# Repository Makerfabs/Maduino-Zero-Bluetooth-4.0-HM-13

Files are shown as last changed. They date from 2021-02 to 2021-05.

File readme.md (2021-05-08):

# Maduino Zero Bluetooth 4.0 HM-13

```c++
/*
Version:		V1.0
Author:			Vincent
Create Date:	2021/5/8
Note:
	
*/
```

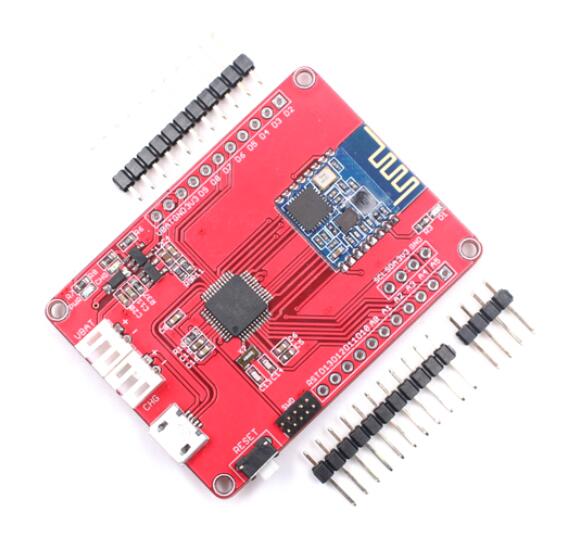
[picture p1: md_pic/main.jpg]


[toc]

# Makerfabs

[Makerfabs home page](https://www.makerfabs.com/)

[Makerfabs Wiki](https://makerfabs.com/wiki/index.php?title=Main_Page)

# Maduino Zero Bluetooth 4.0 HM-13

## Intruduce

Product Link ：[Maduino Zero Bluetooth 4.0 HM-13](https://www.makerfabs.com/maduino-zero-bluetooth-4.0-hm-13.html) 

Wiki Link :  [Maduino Zero Bluetooth 4.0 HM-13](https://www.makerfabs.com/wiki/index.php?title=Maduino_Zero_Bluetooth_4.0_HM-13) 

Maduino Zero HM-13 is an IoT (Internet of things) Solution based on the 32-bit Atmel's SAMD21 MCU and Bluetooth module HM-13. It integrated a micro Controller ATSAMD21G18, BLE module HM-13. The Maduino Zero HM-13 based on the Arduino, users can program it with Arduino IDE, which is very easy especially suit for the none-programmers. There are also guide for users to learn how to create the first IoT project with this board, with which the starters can learn the hardware and programming skill quickly. With this board, you will easy to add text, SMS, and data to your project. It is good for your smart home project or M2M and so on.

## Feature

- BAT Input Voltage: 3.4-4.2V
- ATSAMD21G18, 32-Bit ARM Cortex M0+
- Integrated Power Control System
- Support AT Command
- BLE and SPP Bluetooth Profile Support
- Support USB Power Charge
- Support Micro SD Card
- Interface: I2C/SPI/UART/18*GPIO*
- *Arduino Compatible*
- *Working Temperature: -40 – 85℃*
- *Size: 40mm*55mm

### Front:

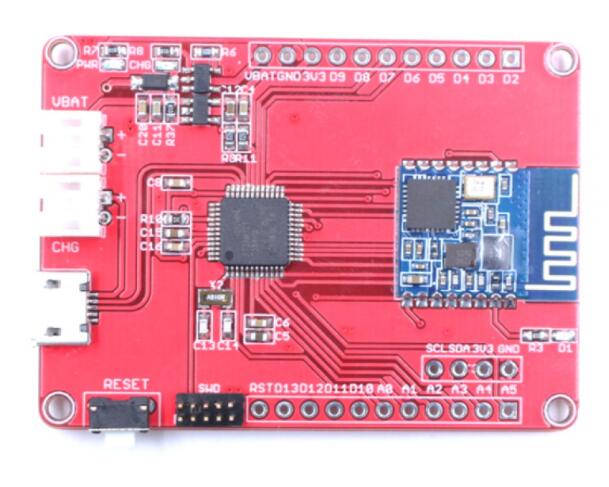
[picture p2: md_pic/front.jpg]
front


### Back:
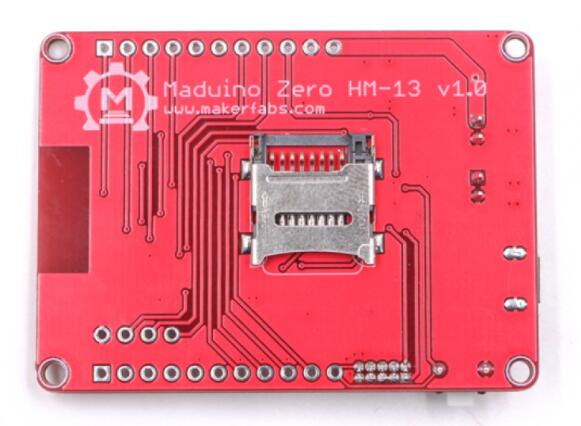
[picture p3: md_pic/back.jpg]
back


## Compiler Options
**If you have any questions，such as how to install the development board, how to download the code, how to install the library. Please refer to :[Makerfabs_FAQ](https://github.com/Makerfabs/Makerfabs_FAQ)**

- Select "Arduino Zero(Native USB port)"

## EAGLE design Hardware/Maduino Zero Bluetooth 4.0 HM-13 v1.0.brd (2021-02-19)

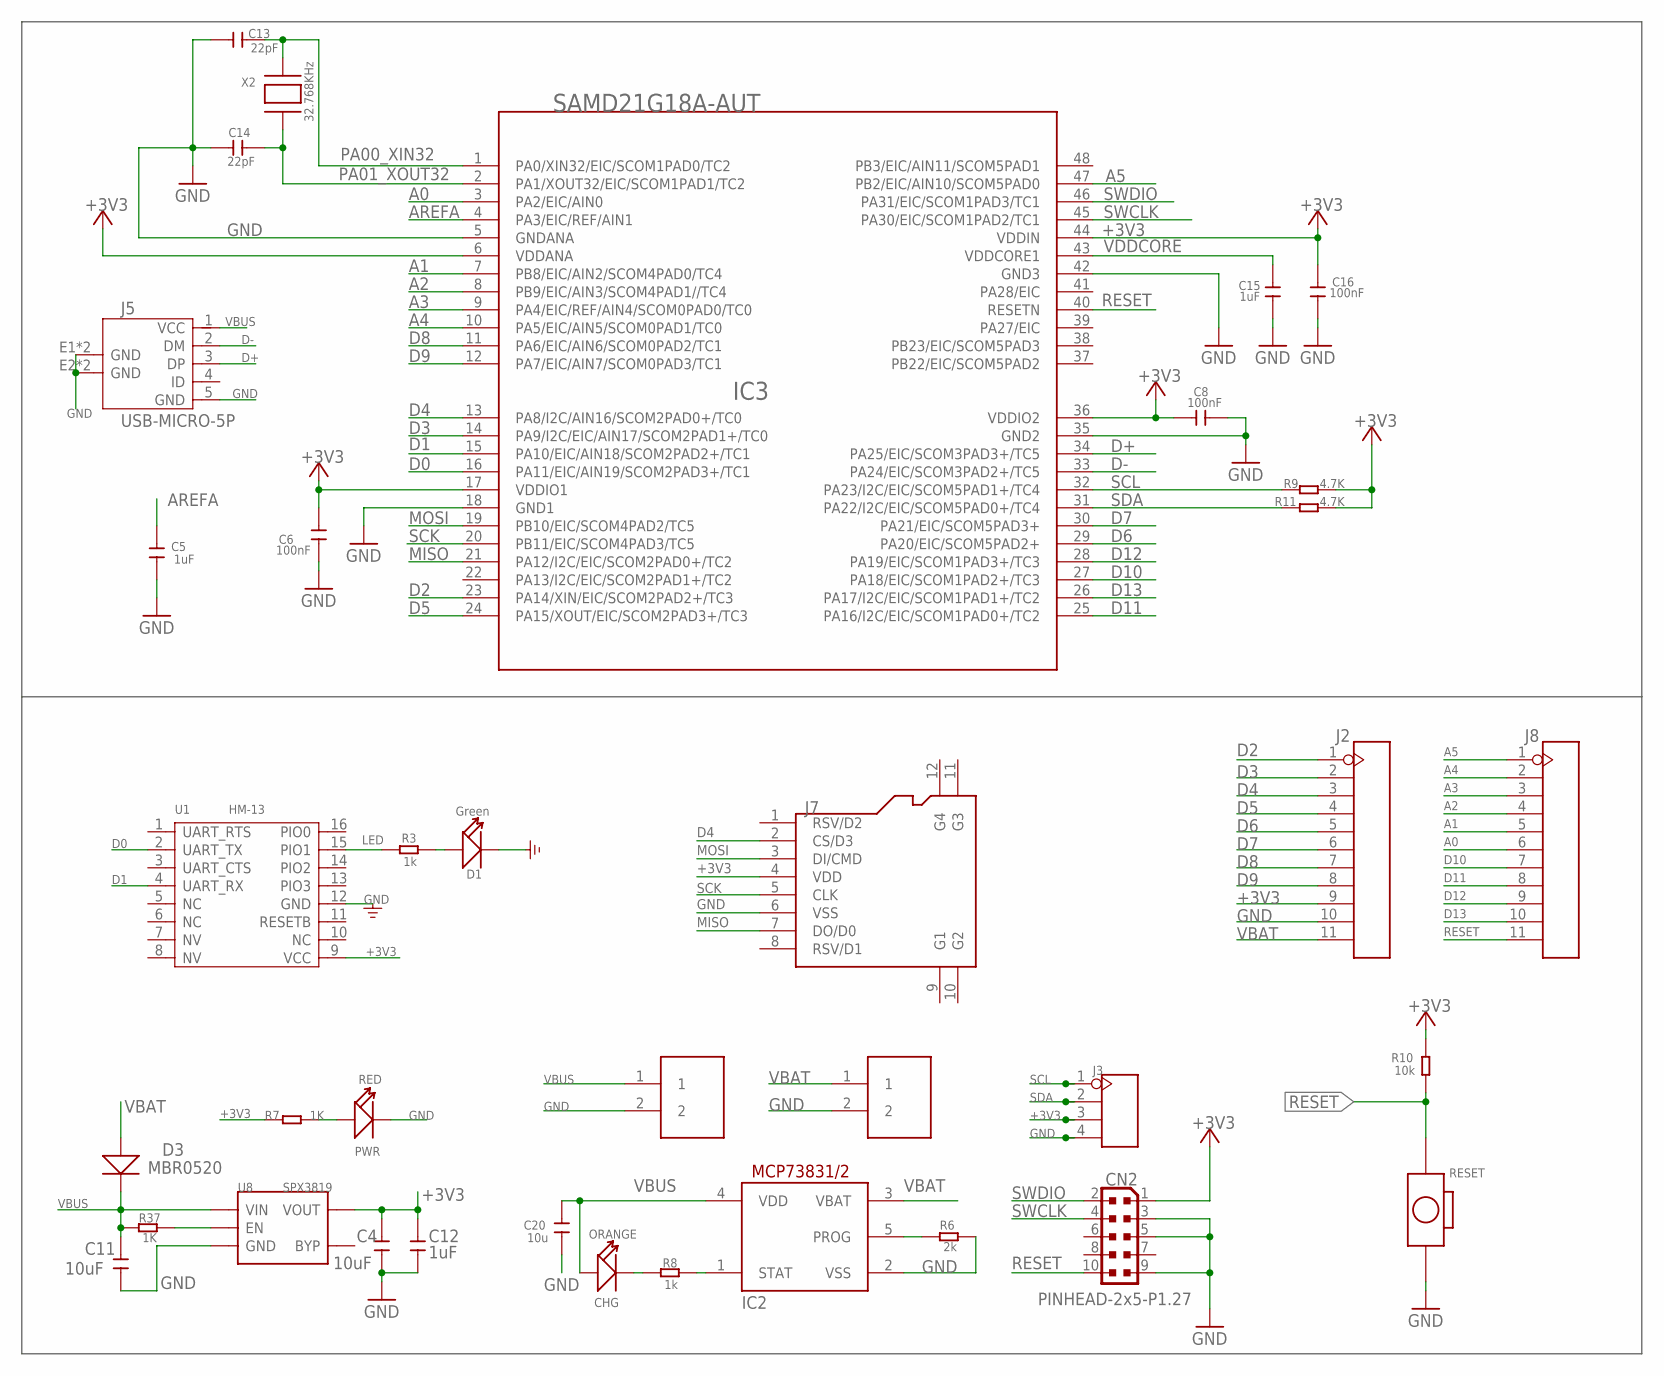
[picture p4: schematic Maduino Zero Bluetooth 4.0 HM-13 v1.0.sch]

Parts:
C4, C11: 10uF; 0603
C5, C12, C15: 1uF; 0603
C6, C8, C16: 100nF; 0603
C13, C14: 22pF; 0603
C20: 10u; 0603
CHG: ORANGE; D0603
CN2: PINHEAD-2x5-P1.27; PINHEAD_2X05_127
D1: Green; LED-0603
D3: MBR0520; SOD123
IC2: MCP73831/OT; SOT23-5L
IC3: SAMD21G18A-AUT; TQFP48-7X7
J1, J6: PH2.0-2P-90-DIP
J2, J8: HEADER-11P-2.54; 11P-2.54
J3: HEADER-4P-60/35MILROUND; 4P-65/35ROUND
J5: USB-MICRO-5P; MICRO-USB-5P
J7: HOLDER-MICROSD-8P; 8P-SMD
PWR: RED; LED-0603
R3, R8: 1k; R0603
R6: 2k; R0603
R7, R37: 1K; R0603
R9, R11: 4.7K; R0603
R10: 10k; R0603
RESET: BOTTON-2P-90D; 2P-7.62X3.56-90D
U1: HM-13; 16P-18.5X13.5X0.8
U8: SPX3819; SOT23-5
X2: 32.768KHz; XTAL3215

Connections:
+3V3: C4.2, C6.2, C8.1, C12.2, C16.1, CN2.1, IC3.6 (VDDANA), IC3.17 (VDDIO1), IC3.36 (VDDIO2), IC3.44 (VDDIN), J2.9, J3.3, J7.4 (VDD), R7.1, R9.2, R10.2, R11.2, U1.9 (VCC), U8.5 (VOUT)
A0: IC3.3 (PA2/EIC/AIN0), J8.6
A1: IC3.7 (PB8/EIC/AIN2/SCOM4PAD0/TC4), J8.5
A2: IC3.8 (PB9/EIC/AIN3/SCOM4PAD1//TC4), J8.4
A3: IC3.9 (PA4/EIC/REF/AIN4/SCOM0PAD0/TC0), J8.3
A4: IC3.10 (PA5/EIC/AIN5/SCOM0PAD1/TC0), J8.2
A5: IC3.47 (PB2/EIC/AIN10/SCOM5PAD0), J8.1
AREFA: C5.1, IC3.4 (PA3/EIC/REF/AIN1)
D0: IC3.16 (PA11/EIC/AIN19/SCOM2PAD3+/TC1), U1.2 (UART_TX)
D1: IC3.15 (PA10/EIC/AIN18/SCOM2PAD2+/TC1), U1.4 (UART_RX)
D2: IC3.23 (PA14/XIN/EIC/SCOM2PAD2+/TC3), J2.1
D3: IC3.14 (PA9/I2C/EIC/AIN17/SCOM2PAD1+/TC0), J2.2
D4: IC3.13 (PA8/I2C/AIN16/SCOM2PAD0+/TC0), J2.3, J7.2 (CS/D3)
D5: IC3.24 (PA15/XOUT/EIC/SCOM2PAD3+/TC3), J2.4
D6: IC3.29 (PA20/EIC/SCOM5PAD2+), J2.5
D7: IC3.30 (PA21/EIC/SCOM5PAD3+), J2.6
D8: IC3.11 (PA6/EIC/AIN6/SCOM0PAD2/TC1), J2.7
D9: IC3.12 (PA7/EIC/AIN7/SCOM0PAD3/TC1), J2.8
D10: IC3.27 (PA18/EIC/SCOM1PAD2+/TC3), J8.7
D11: IC3.25 (PA16/I2C/EIC/SCOM1PAD0+/TC2), J8.8
D12: IC3.28 (PA19/EIC/SCOM1PAD3+/TC3), J8.9
D13: IC3.26 (PA17/I2C/EIC/SCOM1PAD1+/TC2), J8.10
D+: IC3.34 (PA25/EIC/SCOM3PAD3+/TC5), J5.3 (DP)
D-: IC3.33 (PA24/EIC/SCOM3PAD2+/TC5), J5.2 (DM)
GND: C4.1, C5.2, C6.1, C8.2, C11.1, C12.1, C13.2, C14.2, C15.2, C16.2, C20.1, CN2.3, CN2.5, CN2.9, D1.-, IC2.2 (VSS), IC3.5 (GNDANA), IC3.18 (GND1), IC3.35 (GND2), IC3.42 (GND3), J1.2, J2.10, J3.4, J5.5 (GND), J5.E1 (GND), J5.E2 (GND), J5.P1 (GND), J5.P2 (GND), J6.2, J7.6 (VSS), PWR.-, R6.2, RESET.P$2 (2), U1.12 (GND), U8.2 (GND)
LED: R3.1, U1.15 (PIO1)
MISO: IC3.21 (PA12/I2C/EIC/SCOM2PAD0+/TC2), J7.7 (DO/D0)
MOSI: IC3.19 (PB10/EIC/SCOM4PAD2/TC5), J7.3 (DI/CMD)
unnamed: PWR.+, R7.2
unnamed: D1.+, R3.2
unnamed: R37.2, U8.3 (EN)
unnamed: CHG.-, R8.1
unnamed: IC2.1 (STAT), R8.2
unnamed: IC2.5 (PROG), R6.1
PA00_XIN32: C13.1, IC3.1 (PA0/XIN32/EIC/SCOM1PAD0/TC2), X2.P$2
PA01_XOUT32: C14.1, IC3.2 (PA1/XOUT32/EIC/SCOM1PAD1/TC2), X2.P$1
RESET: CN2.10, IC3.40 (RESETN), J8.11, R10.1, RESET.P$1 (1)
SCK: IC3.20 (PB11/EIC/SCOM4PAD3/TC5), J7.5 (CLK)
SCL: IC3.32 (PA23/I2C/EIC/SCOM5PAD1+/TC4), J3.1, R9.1
SDA: IC3.31 (PA22/I2C/EIC/SCOM5PAD0+/TC4), J3.2, R11.1
SWCLK: CN2.4, IC3.45 (PA30/EIC/SCOM1PAD2/TC1)
SWDIO: CN2.2, IC3.46 (PA31/EIC/SCOM1PAD3/TC1)
VBAT: D3.+, IC2.3 (VBAT), J2.11, J6.1
VBUS: C11.2, C20.2, CHG.+, D3.-, IC2.4 (VDD), J1.1, J5.1 (VCC), R37.1, U8.1 (VIN)
VDDCORE: C15.1, IC3.43 (VDDCORE1)

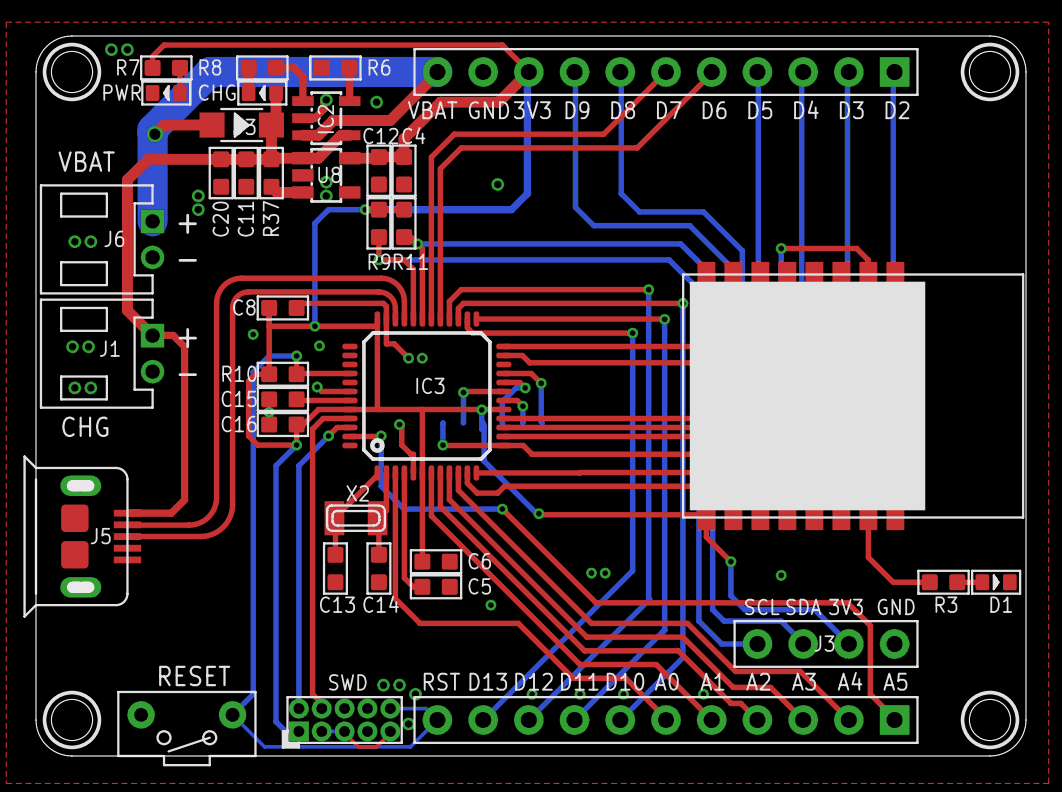
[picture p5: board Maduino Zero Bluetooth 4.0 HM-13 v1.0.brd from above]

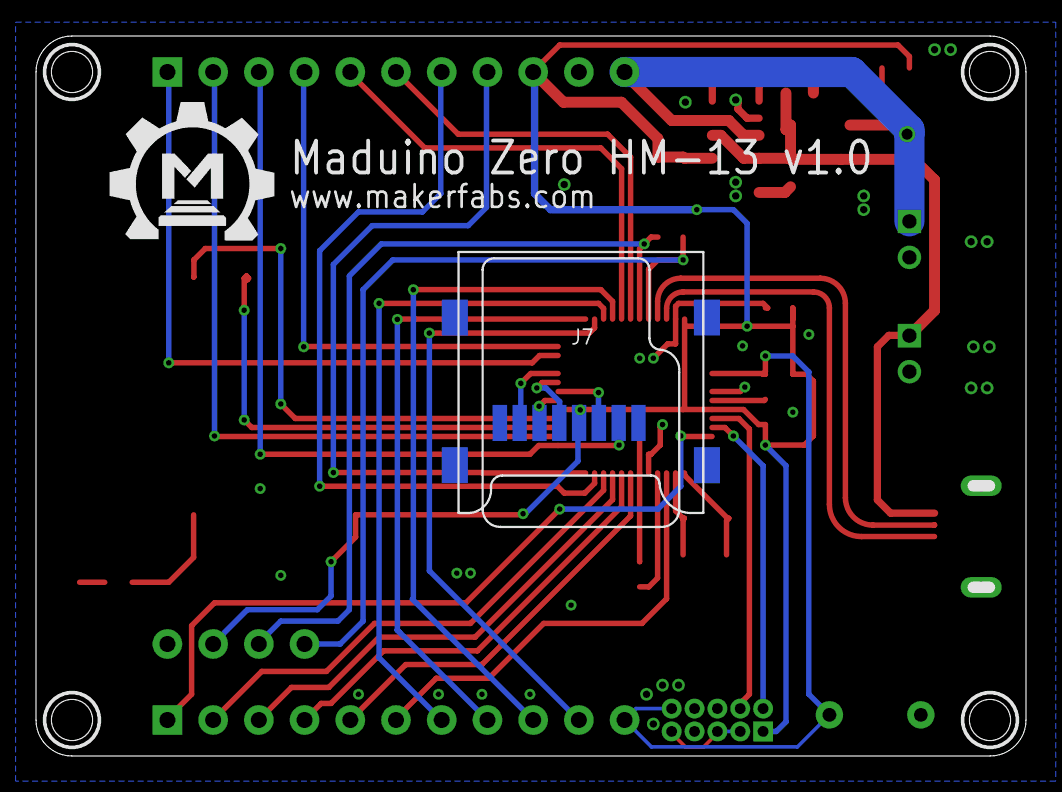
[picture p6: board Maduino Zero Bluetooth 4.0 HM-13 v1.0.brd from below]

Board: 2 copper layers, 55.0 x 40.0 mm, 38 parts (2 on the bottom side), 45 nets.

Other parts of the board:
U$1: MAKERFABS_0.3

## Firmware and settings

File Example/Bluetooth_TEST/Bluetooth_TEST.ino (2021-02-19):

#include <SparkFun_HM1X_Bluetooth_Arduino_Library.h>

HM1X_BT bt;

#define SerialPort SerialUSB // Abstract serial monitor debug port

// BLE and EDR device names
String edrName = "MyEDR";
String bleName = "MyBLE";

void setup() {
  delay(2000);
  SerialPort.begin(9600); // Serial debug port @ 9600 bps
  //while (!SerialPort.available()) ; // Press a key to begin
  //while (SerialPort.available()) SerialPort.read(); // Clear RX buffer

  // bt.begin --
  // in this case takes a HardwareSerial connection and
  // a desired serial baud rate.
  // Returns true on success
  if (bt.begin(Serial1, 9600) == false) {
    SerialPort.println(F("Failed to connect to the HM-13."));
    while (1) ;
  }
  SerialPort.println("Ready to Bluetooth!");

  boolean resetRequired = false; // Reset is required on name change

  String setEdrName = bt.getEdrName();
  // getEdrName returns a string containing EDR device name
  if (setEdrName != edrName) {
    // If set name is different, configure new EDR name
    SerialPort.println("Setting new EDR name");
    // Set EDR device name
    if (bt.setEdrName(edrName) == HM1X_SUCCESS) {
      Serial.println("Set EDR name to " + edrName);
      resetRequired = true;
    }
  } else {
    Serial.println("EDR name is: " + edrName);
  }
  
  // getBleName returns a string containing BLE device name
  String setBleName = bt.getBleName();
  if (setBleName != bleName) {
    // If set name is different, configure new BLE name
    SerialPort.println("Setting new BLE name");
    // Set BLE device name
    if (bt.setBleName(bleName) == HM1X_SUCCESS) {
      SerialPort.println("Set BLE name");
      resetRequired = true;
    }
  } else {
    SerialPort.println("BLE name is: " + setBleName);
  }
  
  SerialPort.println("EDR address: " + bt.edrAddress());
  SerialPort.println("BLE address: " + bt.bleAddress());

  if (resetRequired) {
    SerialPort.println("Resetting BT module. Wait a few seconds.");
    bt.reset();
  }
}

void loop() {
  if (bt.available()) {
    SerialPort.write((char) bt.read());
  }
  if (SerialPort.available()) {
    bt.write((char) SerialPort.read());
  } 
}

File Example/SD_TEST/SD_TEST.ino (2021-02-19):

#include <SPI.h>
#include <SD.h>

File myFile;

#define SD_CS  4

void setup() {
  // Open serial communications and wait for port to open:
  Serial.begin(9600);
  while (!Serial) {
    ; // wait for serial port to connect. Needed for native USB port only
  }


  Serial.print("Initializing SD card...");

  if (!SD.begin(SD_CS)) {
    Serial.println("initialization failed!");
    while (1);
  }
  Serial.println("initialization done.");

  // open the file. note that only one file can be open at a time,
  // so you have to close this one before opening another.
  myFile = SD.open("test.txt", FILE_WRITE);

  // if the file opened okay, write to it:
  if (myFile) {
    Serial.print("Writing to test.txt...");
    myFile.println("testing 1, 2, 3.");
    // close the file:
    myFile.close();
    Serial.println("done.");
  } else {
    // if the file didn't open, print an error:
    Serial.println("error opening test.txt");
  }

  // re-open the file for reading:
  myFile = SD.open("test.txt");
  if (myFile) {
    Serial.println("test.txt:");

    // read from the file until there's nothing else in it:
    while (myFile.available()) {
      Serial.write(myFile.read());
    }
    // close the file:
    myFile.close();
  } else {
    // if the file didn't open, print an error:
    Serial.println("error opening test.txt");
  }
}

void loop() {
  // nothing happens after setup
}
